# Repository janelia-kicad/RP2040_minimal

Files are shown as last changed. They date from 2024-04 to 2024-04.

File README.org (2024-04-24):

# This file is generated automatically from metadata
# File edits may be overwritten!
- Project Name: RP2040_minimal
- Synopsis: This minimal design example is intended to demonstrate how you can get started with your own RP2040 based PCB designs.
- Documentation Version: 1.0.0
- Pcb Version: 1.0
- Enclosure Version: 1.0
- Supplemental BOM Version: 1.0
- Release Date: 2024-04-24
- Creation Date: 2024-03-20
- Kicad Version: 7.0.11
- License: BSD-3-Clause
- URL: https://github.com/janelia-kicad/RP2040_minimal
- Author: Peter Polidoro
- Email: peter@polidoro.io
- Copyright: 2024 Howard Hughes Medical Institute
- References:
  - [[https://www.raspberrypi.com/products/raspberry-pi-pico/][Raspberry Pi Pico]]



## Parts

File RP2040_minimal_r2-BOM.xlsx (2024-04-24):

RP2040_minimal_r2 BOM
Item | Quantity | Reference | Part | Voltage | Current | Power | Material | Size | Tolerance | Manufacturer | Manuf. Part # | Description | Notes
1 | 3 | C1,C4,C17 | 10u | 16V |  |  | X5R | 0805_2012Metric | 10% | Murata | GRM21BR61C106KE15K | CAP CER 10UF 16V X5R 0805 | Or equivalent
2 | 2 | C2, C3 | 15p | 50V |  |  | C0G | 0402_1005Metric | 5% | Murata | GCM1555C1H150JA16D | CAP CER 15PF 50V C0G/NP0 0402 | Or equivalent
3 | 10 | C5, C6, C7, C9, C11, C12, C13, C14, C15, C16 | 100n | 25V |  |  | X7R | 0402_1005Metric | 10% | Murata | GRM155R71E104KE14J | CAP CER 0.1UF 25V X7R 0402 | Or equivalent
4 | 2 | C8, C10 | 1u | 10V |  |  | X6S | 0402_1005Metric | 10% | Murata | GRM155C81A105KA12D | CAP CER 1UF 10V X6S 0402 | Or equivalent
5 | 1 | J1 | USB_B_Micro |  |  |  |  |  |  | Amphenol | 10103594-0001LF | CONN RCPT USB2.0 MICRO B SMD R/A | Or equivalent
6 | 1 | J2 | 1x2 way header |  |  |  |  |  |  | Samtec | TSW-102-23-T-S | 2.54mm pin header 1x2 | Or equivalent
7 | 2 | J3, J4 | 2x18 way header |  |  |  |  |  |  | Samtec | TSW-118-23-T-D | 2.54mm pin header 2x18 | Or equivalent
8 | 2 | R1, R5 | 1k |  |  | 63mW |  | 0402_1005Metric | 1% | Yageo | RC0402FR-071KP | RES SMD 1K OHM 1% 1/16W 0402 | Or equivalent
9 | 1 | R2 | DNF |  |  |  |  | 0402_1005Metric |  |  |  |  | Do Not Fit
10 | 2 | R3, R4 | 27.4 |  |  | 63mW |  | 0402_1005Metric | 1% | Yageo | RC0402FR-0727R4L | RES SMD 27.4 OHM 1% 1/16W 0402 | Or equivalent
11 | 1 | U1 | NCP1117-3.3 |  |  |  |  | SOT-223-3 |  | ON Semiconductor | NCP1117ST33T3G | IC REG LINEAR 3.3V 1A SOT223
12 | 1 | U2 | W25Q128JVS |  |  |  |  | SOIC-8 |  | Winbond | W25Q128JVSIQ TR | IC FLASH 128M SPI 133MHZ 8SOIC
13 | 1 | U3 | RP2040 |  |  |  |  | QFN56 |  | Raspberry Pi | RP2040
14 | 1 | Y1 | ABM8-272-T3 |  |  |  |  | SMD_3225 |  | Abracon | ABM8-272-T3 | CRYSTAL 12.0000MHZ 3.2x2.5MM SMD

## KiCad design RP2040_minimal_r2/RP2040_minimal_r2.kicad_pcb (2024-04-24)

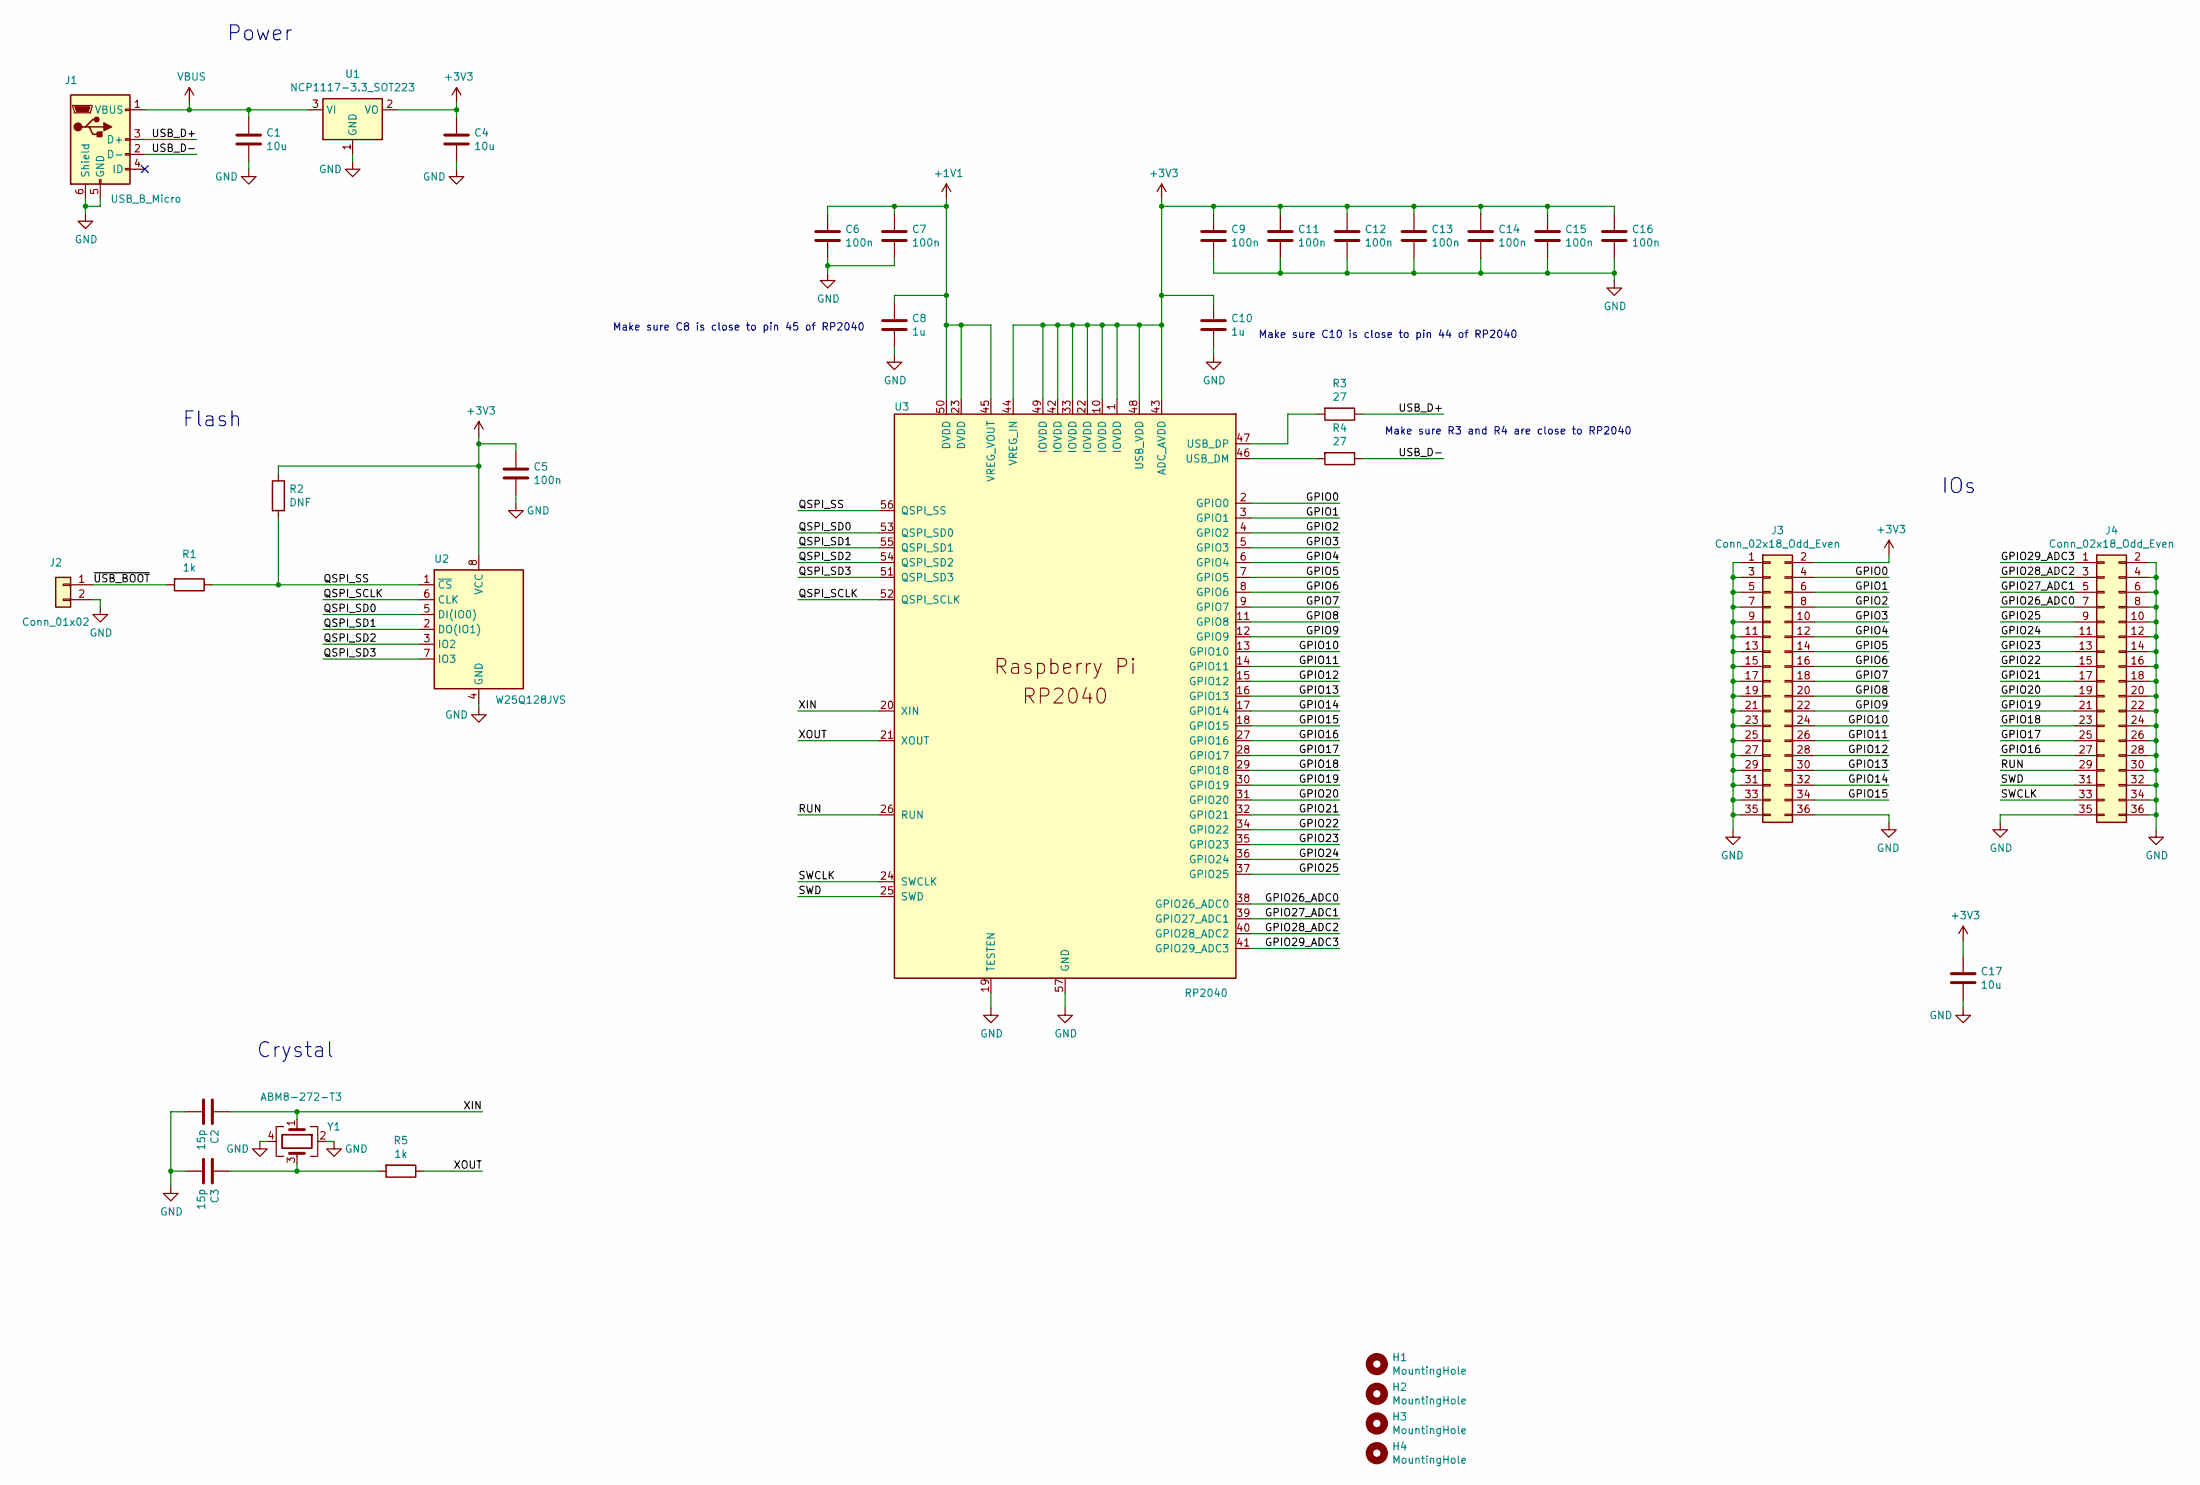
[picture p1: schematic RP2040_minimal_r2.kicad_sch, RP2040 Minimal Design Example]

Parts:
C1, C4, C17: 10u; C_0805_2012Metric
C2, C3: 15p; C_0402_1005Metric
C5, C6, C7, C9, C11, C12, C13, C14, C15, C16: 100n; C_0402_1005Metric
C8, C10: 1u; C_0402_1005Metric
H1, H2, H3, H4: MountingHole; MountingHole_2.7mm_M2.5
J1: USB_B_Micro; USB_Micro-B_Amphenol_10103594-0001LF_Horizontal_modified
J2: Conn_01x02; PinHeader_1x02_P2.54mm_Vertical
J3, J4: Conn_02x18_Odd_Even; PinHeader_2x18_P2.54mm_Vertical
R1, R5: 1k; R_0402_1005Metric
R2: DNF; R_0402_1005Metric
R3, R4: 27; R_0402_1005Metric
U1: NCP1117-3.3_SOT223; SOT-223-3_TabPin2
U2: W25Q128JVS; SOIC-8_5.23x5.23mm_P1.27mm
U3: RP2040; RP2040-QFN-56
Y1: ABM8-272-T3; Crystal_SMD_3225-4Pin_3.2x2.5mm

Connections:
+1V1: C6.1, C7.1, C8.1, U3.23 (DVDD), U3.45 (VREG_VOUT), U3.50 (DVDD)
+3V3: C4.1, C5.1, C9.1, C10.1, C11.1, C12.1, C13.1, C14.1, C15.1, C16.1, C17.1, J3.2, R2.1, U1.2 (VO), U2.8 (VCC), U3.1 (IOVDD), U3.10 (IOVDD), U3.22 (IOVDD), U3.33 (IOVDD), U3.42 (IOVDD), U3.43 (ADC_AVDD), U3.44 (VREG_IN), U3.48 (USB_VDD), U3.49 (IOVDD)
/GPIO0: J3.4, U3.2 (GPIO0)
/GPIO1: J3.6, U3.3 (GPIO1)
/GPIO2: J3.8, U3.4 (GPIO2)
/GPIO3: J3.10, U3.5 (GPIO3)
/GPIO4: J3.12, U3.6 (GPIO4)
/GPIO5: J3.14, U3.7 (GPIO5)
/GPIO6: J3.16, U3.8 (GPIO6)
/GPIO7: J3.18, U3.9 (GPIO7)
/GPIO8: J3.20, U3.11 (GPIO8)
/GPIO9: J3.22, U3.12 (GPIO9)
/GPIO10: J3.24, U3.13 (GPIO10)
/GPIO11: J3.26, U3.14 (GPIO11)
/GPIO12: J3.28, U3.15 (GPIO12)
/GPIO13: J3.30, U3.16 (GPIO13)
/GPIO14: J3.32, U3.17 (GPIO14)
/GPIO15: J3.34, U3.18 (GPIO15)
/GPIO16: J4.27, U3.27 (GPIO16)
/GPIO17: J4.25, U3.28 (GPIO17)
/GPIO18: J4.23, U3.29 (GPIO18)
/GPIO19: J4.21, U3.30 (GPIO19)
/GPIO20: J4.19, U3.31 (GPIO20)
/GPIO21: J4.17, U3.32 (GPIO21)
/GPIO22: J4.15, U3.34 (GPIO22)
/GPIO23: J4.13, U3.35 (GPIO23)
/GPIO24: J4.11, U3.36 (GPIO24)
/GPIO25: J4.9, U3.37 (GPIO25)
/GPIO26_ADC0: J4.7, U3.38 (GPIO26_ADC0)
/GPIO27_ADC1: J4.5, U3.39 (GPIO27_ADC1)
/GPIO28_ADC2: J4.3, U3.40 (GPIO28_ADC2)
/GPIO29_ADC3: J4.1, U3.41 (GPIO29_ADC3)
/QSPI_SCLK: U2.6 (CLK), U3.52 (QSPI_SCLK)
/QSPI_SD0: U2.5 (DI(IO0)), U3.53 (QSPI_SD0)
/QSPI_SD1: U2.2 (DO(IO1)), U3.55 (QSPI_SD1)
/QSPI_SD2: U2.3 (IO2), U3.54 (QSPI_SD2)
/QSPI_SD3: U2.7 (IO3), U3.51 (QSPI_SD3)
/QSPI_SS: R1.1, R2.2, U2.1 (~CS), U3.56 (QSPI_SS)
/RUN: J4.29, U3.26 (RUN)
/SWCLK: J4.33, U3.24 (SWCLK)
/SWD: J4.31, U3.25 (SWD)
/USB_D+: J1.3 (D+), R3.1
/USB_D-: J1.2 (D-), R4.1
/XIN: C2.1, U3.20 (XIN), Y1.1
/XOUT: R5.1, U3.21 (XOUT)
/~USB_BOOT: J2.1, R1.2
GND: C1.2, C2.2, C3.2, C4.2, C5.2, C6.2, C7.2, C8.2, C9.2, C10.2, C11.2, C12.2, C13.2, C14.2, C15.2, C16.2, C17.2, J1.5 (GND), J1.6 (Shield), J2.2, J3.1, J3.3, J3.5, J3.7, J3.9, J3.11, J3.13, J3.15, J3.17, J3.19, J3.21, J3.23, J3.25, J3.27, J3.29, J3.31, J3.33, J3.35, J3.36, J4.2, J4.4, J4.6, J4.8, J4.10, J4.12, J4.14, J4.16, J4.18, J4.20, J4.22, J4.24, J4.26, J4.28, J4.30, J4.32, J4.34, J4.35, J4.36, U1.1 (GND), U2.4 (GND), U3.19 (TESTEN), U3.57 (GND), Y1.2, Y1.4
unnamed: C3.1, R5.2, Y1.3
unnamed: R4.2, U3.46 (USB_DM)
unnamed: R3.2, U3.47 (USB_DP)
VBUS: C1.1, J1.1 (VBUS), U1.3 (VI)

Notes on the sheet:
IOs
Power
Crystal
Make sure C8 is close to pin 45 of RP2040
Make sure C10 is close to pin 44 of RP2040
Make sure R3 and R4 are close to RP2040
Flash


Board: 2 copper layers, 52.0 x 51.0 mm, 34 parts (0 on the bottom side), 51 nets.
